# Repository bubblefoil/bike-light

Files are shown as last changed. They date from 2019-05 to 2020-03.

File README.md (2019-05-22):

# Cargo bike illumination

Cusomized bicycle RGB LED strip illumination controlled by Arduino UNO

# TODO
## Rezimy
- __Nocni:__ svitit vpredu max intenzitou (cca 6 LED z kraje), zbytek do konce nosice prichciple. To same v cervene vzadu.
- __Denni:__ To same co nocni, akorat ty prichciple nesviti vubec (stejne by to nebylo videt)
- __Parkovacky:__ sviti to prichciple cele, pricemz by bylo hezke umet menit intenzitu.
- __Blinkry:__ Max intenzivne oranzove z kraje prvnich cca 12LED prerusovane (oranzova/zhasnuto) a zbytek pri dennim nic a nocnim prichciple (bila ^ cervena)

## Rezimy 2.0

- __OFF:__ Vse 0%. Nejaka indikace?
- __Auto:__
  - Stred: 100%
  - Strany: Podle senzoru. Viz tabulka niz. Moznost menit citlivost stejne jako nastaveni jasu, tj. drzenim prepinace rezimu. Melo by stacit posouvat hranici sero/svetlo, kdy se strany vypinaji.
- __Manual:__
  - Vse podle hodnoty nastavene drzenim prepinace rezimu: 0-100%
  - 0-50%
    - Stred: 10-100%
    - Strany: Vypnute
  - 50-100%
    - Stred: 100%
    - Strany: 0-100%
- __Parking:__
  - Jas podle hodnoty nastavene drzenim prepinace rezimu: 0-100%
  - Vse sviti stejne
- __Usporny rezim:__
  - Jas podle hodnoty nastavene drzenim prepinace rezimu: 0-100%
  - Stred: Blikani (plynule pulzovani? Animace jednotlivych LED?)
  - Strany: Vypnute
  - Zmensit jas/sirku blinkru?

| Senzor | Jas [%] |
| --- | --- |
| Tma | ~1 |
| Sero | ~25 |
| Svetlo | 0 |

> To by bylo v prvni verzi vsechno. Couvacky, signalizace zamykani, kradeni, svetelna houkacka, vykreslovani bassu hudby apod.nechame na pozdeji ;)

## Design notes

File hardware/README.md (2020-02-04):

# Controller HW diagram

The cargo bike is already equiped with its own 12V battery.

Controller is programmed to work with 3 switches. A couple for turn signals and one with press/hold functions to switch light modes and control brightness.
There are [motorcycle switches like this](https://www.banggood.com/22mm-Handlebar-Light-Horn-OnOff-Signal-Indicator-Switch-For-Motorcycle-E-bike-p-1211467.html) available on the market.

Controller schema - SVG

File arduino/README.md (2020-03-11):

# Lights control unit software

Arduino application / LED strip driver.
Supplies data for WS2812B based addressable LED strips.
Uses 3 buttons as input, one for selecting light mode and changing brightness, the other two activate turn signals.

Additionally, the unit is prepared to measure ambient light by a photoresistor and battery voltage level.

It is planned to decode data on serial input as commands so the unit may be controlled via HT-05 bluetooth module. This will require solving the conflict with FastLED, which disables interrupts during feeding the strips and incoming serial data are lost.

## Development

Application is developed with [PlatformIO](https://platformio.org/platformio-ide), which has better dependency management and works with clean C++ code instead of special .ino files.

## TODO List

* Ligths off when blinking in every mode
* Implement power saving mode - blinking
* Switch to power saving mode on low battery voltage
* Less bright blinkers in power saving mode
* Fix Serial issue #2
* Animate blinkers
* Animate light changes

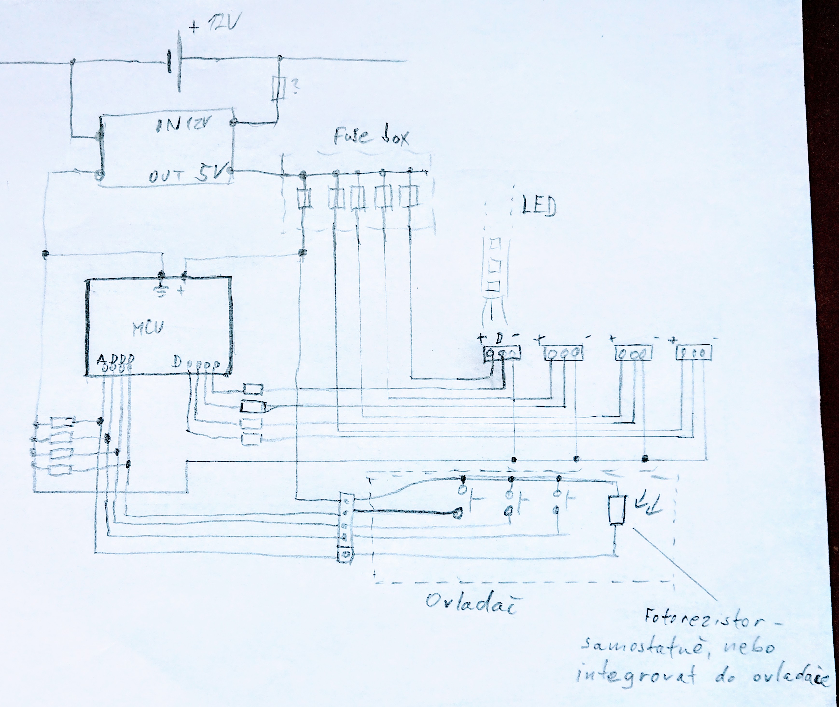
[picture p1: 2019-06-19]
hardware/Sketch.JPG

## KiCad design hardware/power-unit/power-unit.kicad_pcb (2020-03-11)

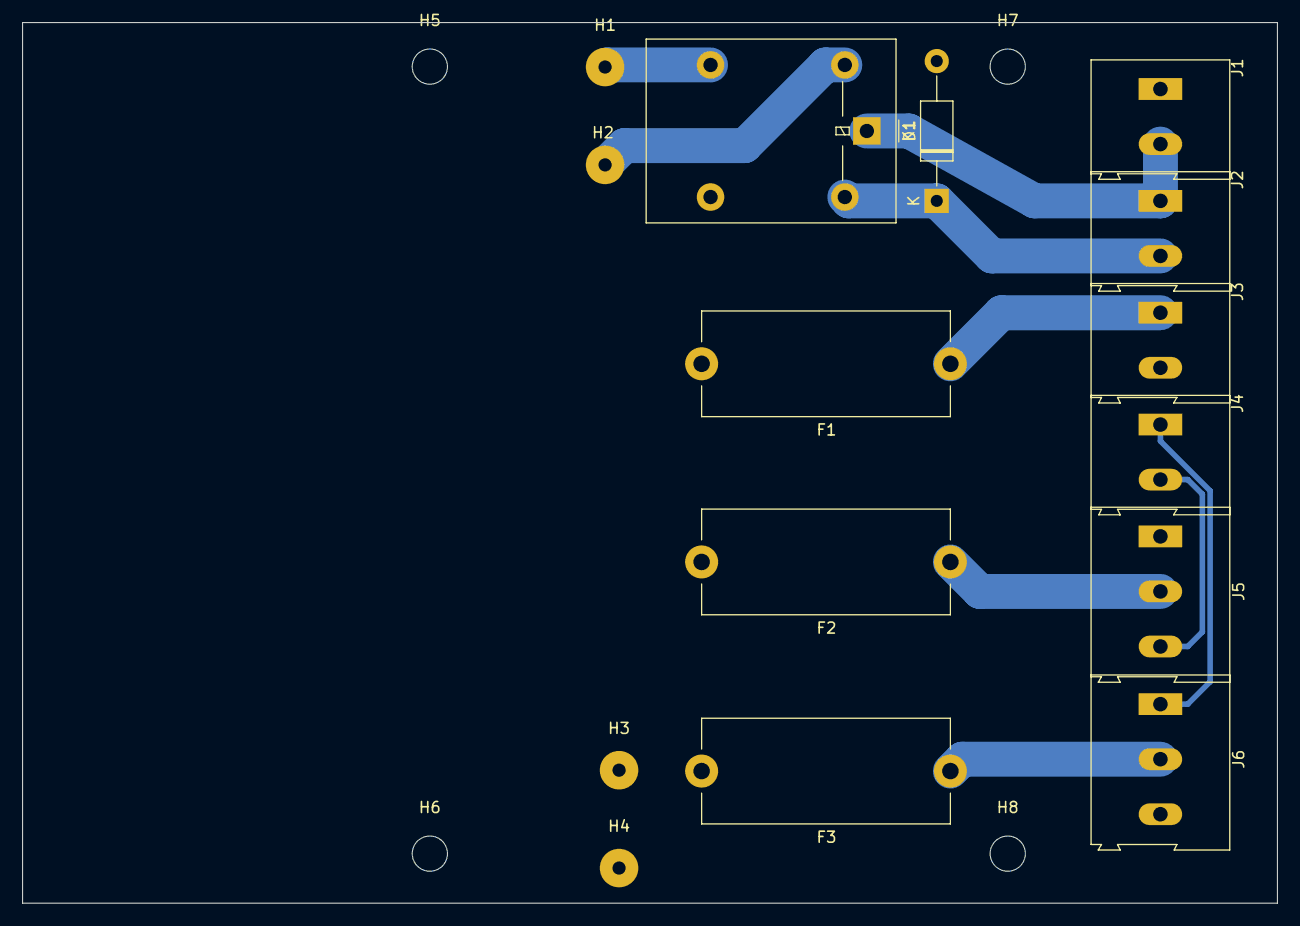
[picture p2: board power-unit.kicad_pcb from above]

Board: 2 copper layers, 114.0 x 80.0 mm, 19 parts (0 on the bottom side), 11 nets.

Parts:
D1: D; D_DO-41_SOD81_P12.70mm_Horizontal
F1: 5A; Fuseholder_Cylinder-5x20mm_Stelvio-Kontek_PTF78_Horizontal_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
F2, F3: 2.5A; Fuseholder_Cylinder-5x20mm_Stelvio-Kontek_PTF78_Horizontal_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
H1: VCC; SolderWirePad_1x01_Drill1.2mm
H2, H4: GND; SolderWirePad_1x01_Drill1.2mm
H3: +5V; SolderWirePad_1x01_Drill1.2mm
H5, H6, H7, H8: MountingHole; MountingHole_3.2mm_M3
J1: VCC; TerminalBlock_Altech_AK300-2_P5.00mm
J2: PWR Switch; TerminalBlock_Altech_AK300-2_P5.00mm
J3: 5V out; TerminalBlock_Altech_AK300-2_P5.00mm
J4: Rear LED data; TerminalBlock_Altech_AK300-2_P5.00mm
J5: LED left; TerminalBlock_Altech_AK300-3_P5.00mm
J6: LED right; TerminalBlock_Altech_AK300-3_P5.00mm
K1: G5LE-1; Relay_SPDT_Omron-G5LE-1

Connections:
+5V: F1.2, F2.2, F3.2, H3.1
BAT+: J1.2, J2.1, K1.1
GND: H4.1, J3.2, J5.1, J6.3
GNDPWR: D1.2, H2.1, J1.1, K1.2
unnamed: F1.1, J3.1
unnamed: F2.1, J5.2
unnamed: F3.1, J6.2
unnamed: H1.1, K1.3
unnamed: J4.1, J6.1
unnamed: J4.2, J5.3
PRWSW: D1.1, J2.2, K1.5

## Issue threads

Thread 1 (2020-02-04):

Change buttons to PullUp and use Arduino's integrated PullUp resistor

bubblefoil, 2020-02-04:
No need for external pull-down resistors!
https://www.brainy-bits.com/arduino-input-pullup-tutorial/

Closed 2020-02-21.

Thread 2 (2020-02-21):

Do not update LED strips unless colors change to enable reading from Serial

bubblefoil, 2020-02-21:
https://github.com/FastLED/FastLED/wiki/Interrupt-problems

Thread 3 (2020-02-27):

Prevent backpowering AVR via battery voltmeter

bubblefoil, 2020-02-27:
When the main power switch is flipped to ON, it will connect the battery voltage to an analog pin of AVR. With some delay, this voltage activates a relay which connects battery to the DC-DC converter, which powers AVR. During this delay, AVR may receive power from the analog input and burn.
This may not apply with the high-resistance voltage divider in the way, but check this out before connecting the battery.
https://forum.arduino.cc/index.php?topic=65840.0

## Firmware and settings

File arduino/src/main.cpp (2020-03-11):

#include <Arduino.h>
#include <FastLED.h>
#include "Button.h"
#include "Light.h"

// Total number of LEDs in the strip
#define NUM_LEDS 36
// Control the LED strips
#define DATA_PIN_FL 2
#define DATA_PIN_FR 3
#define DATA_PIN_BL 5
#define DATA_PIN_BR 4

// TBD - Bluetooth communication
#define RX 6
#define TX 7

// Digital input pins for buttons
#define pinLightMode 11
#define pinTurnLeft 10
#define pinTurnRight 12

const int pinPhotoResistor = A0;
const int pinBatteryVoltage = A4;

// Default light mode. Set to OFF mainly for development with just USB power.
const byte OFF = 0;
byte lightMode = OFF;

// Millis until button press is interpreted as holding.
const unsigned int holdThresholdTime = 300;
// Last mode button hold duration. Used to find time increment for gradual brightness change.
unsigned int lastHoldTime = 0;
// Sign of the brightness increment. Flipped every time the button is held and released. Do not use byte, it is unsigned!
int brightnessChangeDirection = 1;

//Left blinker
const byte LEFT = 11;
//Right blinker
const byte RIGHT = 12;
//Blinker light hue in the range from 0 - red to 255 - red again
const byte BLINKER_HUE = 24;
// Total duration of a single ON/OFF blink in milliseconds.
const unsigned long turnSignalInterval = 1000L;

// Number of head/tail light LEDs. These shine at full brightness.
const int N_FRONTAL = 6;
// Number of turn signal LEDs
const byte N_TURN_SIG = 12;

// Memory for all LED values
CRGB ledsFL[NUM_LEDS];
CRGB ledsFR[NUM_LEDS];
CRGB ledsBL[NUM_LEDS];
CRGB ledsBR[NUM_LEDS];

//LED arrays
Lights lights = Lights(ledsFL, ledsFR, ledsBL, ledsBR, NUM_LEDS, NUM_LEDS, NUM_LEDS, NUM_LEDS);

// Individual light modes.
// Classes implement abstract class LightMode with updateLights and changeBrightness methods.
LightsOff lightsOff = LightsOff(lights);
AdaptiveToAmbientLight adaptiveToAmbientLight = AdaptiveToAmbientLight(lights, pinPhotoResistor, N_FRONTAL);
ManualBrightnessLight manualBrightnessLight = ManualBrightnessLight(lights, N_FRONTAL);
ParkingLights parkingLights = ParkingLights(lights);

/** Array of pointers to the light modes. Cycled through when switching modes.
* These have to be pointers, otherwise modes would be stored and used by value, but through a LightMode referece,
* which causes "object slicing" and caling the base method instead of derived.
* https://stackoverflow.com/questions/274626/what-is-object-slicing
*/
LightMode *lightModes[] = {
    &lightsOff,
    &adaptiveToAmbientLight,
    &manualBrightnessLight,
    &parkingLights,
};

// Forward prototype declaration because of the default parameter.
void updateLights(bool show = true);

//Temporary variable to test brightness control.
byte globalBrightness = 255;

// Controls light mode. Holding the button changes brightness.
Button buttonLightMode = Button(pinLightMode, BUTTON_PULLUP_INTERNAL, true, 50);
Button buttonBlinkerLeft = Button(pinTurnLeft, BUTTON_PULLUP_INTERNAL, true, 50);
Button buttonBlinkerRight = Button(pinTurnRight, BUTTON_PULLUP_INTERNAL, true, 50);

/**
 * Changes light mode to the next one, in a circle.
 */
void nextLightMode()
{
  lightMode++;
  lightMode %= (sizeof(lightModes) / sizeof(LightMode *));
  Serial.print("Light mode: ");
  Serial.println(lightMode);
  updateLights();
}

void nextLightModeHandler(Button &b)
{
  nextLightMode();
}

/**
 * Release button handler which is active during holding event.
 * When the button is release after a hold event, the release hanlder is set back to its normal light mode change function.
 * Also the brightness change direction is flipped so when the button is held again, it makes the opposite change of brightness.
 */
void activateLightModeChangeHandler(Button &b)
{
  brightnessChangeDirection *= -1;
  Serial.print("*^ ");
  Serial.println(brightnessChangeDirection);
  b.releaseHandler(nextLightModeHandler);
}

/**
 * When a hold event is triggered, this hold handler changes Button release handler not to change Light mode,
 * because user is changing brightness. 
 */
void activateBrightnessChangeMode(Button &b)
{
  // Deactivate click handler to ignore the last click, triggered by button hold.
  // This handler will reactivate the original light mode change click handler.
  b.releaseHandler(activateLightModeChangeHandler);
}

void turnOffBlinker(Button &b)
{
  updateLights();
}

void readAmbientLight(Button &b)
{
  Serial.print("Light:");
  Serial.println(analogRead(pinPhotoResistor));
}

void processSerialInput()
{
  // FIXME: Serial input is busy when FastLED writes to strips.
  // https://github.com/FastLED/FastLED/wiki/Interrupt-problems
  while (Serial.available() > 0)
  {
    String receivedText = Serial.readString();
    Serial.println(receivedText);
    char state = receivedText[0];
    if (state >= '0' && state < (sizeof(lightModes) / sizeof(LightMode *)))
    {
      lightMode = (byte)state;
    }
    else
    {
      switch (state)
      {
      case '+':
        lightModes[lightMode]->brightnessChange(100, MORE);
        break;
      case '-':
        lightModes[lightMode]->brightnessChange(100, LESS);
        break;
      case 'm':
        nextLightMode();
        break;
      default:
        break;
      }
    }
  }
}

void handleBlinkers();
void blink(unsigned int blinkerOnTime, byte side);
void frontLeft(const CHSV &col);
void frontRight(const CHSV &col);
void rearLeft(const CHSV &col);
void rearRight(const CHSV &col);
void frontalArea();

/**
 * Initialization when Arduino is turned on.
*/
void setup()
{
  Serial.begin(9600);
  Serial.println("Arduino ON.");

  pinMode(pinPhotoResistor, INPUT); // Set pinPhotoResistor - A0 pin as an input (optional)

  // Setup buttons
  buttonLightMode.releaseHandler(nextLightModeHandler);
  buttonLightMode.holdHandler(activateBrightnessChangeMode, 300);
  //TODO try reactivating mode change on release. Modify the lib to keep firing hold events. Use this handler to change brightness.

  //Make sure lights are reset when a blinker is turned off.
  buttonBlinkerLeft.releaseHandler(turnOffBlinker);
  buttonBlinkerRight.releaseHandler(turnOffBlinker);

  // Temp ambient light sensor test
  buttonBlinkerLeft.pressHandler(readAmbientLight);
  buttonBlinkerRight.pressHandler(readAmbientLight);

  FastLED.addLeds<NEOPIXEL, DATA_PIN_FL>(ledsFL, NUM_LEDS);
  FastLED.addLeds<NEOPIXEL, DATA_PIN_FR>(ledsFR, NUM_LEDS);
  FastLED.addLeds<NEOPIXEL, DATA_PIN_BL>(ledsBL, NUM_LEDS);
  FastLED.addLeds<NEOPIXEL, DATA_PIN_BR>(ledsBR, NUM_LEDS);

  updateLights();
}

/**
 * Main Arduino's infinite loop.
*/
void loop()
{
  buttonLightMode.process();
  void processSerialInput();

  //todo Cannot use heldFor() because it checks whether hold event has already been fired. Use better timing here.
  unsigned int holdTime = buttonLightMode.holdTime();
  if (buttonLightMode.heldFor(holdThresholdTime) && holdTime > lastHoldTime)
  {
    lightModes[lightMode]->brightnessChange(holdTime - lastHoldTime, brightnessChangeDirection);
    lastHoldTime = holdTime;
  }
  else
  {
    lastHoldTime = holdThresholdTime;
  }

  updateLights(false);
  handleBlinkers();
  FastLED.show();
  FastLED.delay(10);
}

void handleBlinkers()
{
  if (buttonBlinkerLeft.isPressed())
  {
    blink(buttonBlinkerLeft.holdTime(), LEFT);
  }
  else if (buttonBlinkerRight.isPressed())
  {
    blink(buttonBlinkerRight.holdTime(), RIGHT);
  }
}

/**
 * Returns true if we are in the first half of the blinker interval,
 * measured since the blinker was switched on.
 */
bool getBlinkerLightState(unsigned int switchOnTime)
{
  // Less than half the blinker interval elapsed?
  return (switchOnTime % turnSignalInterval < (turnSignalInterval / 2));
}

void blink(unsigned int blinkerOnTime, byte side)
{
  //Is the blinker light on or off at the moment?
  bool blinkerState = getBlinkerLightState(blinkerOnTime);

  if (!blinkerState)
  {
    updateLights(false);
  }

  byte brightness = blinkerState ? 255 : 0;
  CHSV blinkerColor = CHSV(BLINKER_HUE, 255, brightness);
  if (side == RIGHT)
  {
    frontRight(blinkerColor);
    rearRight(blinkerColor);
  }
  else if (side == LEFT)
  {
    frontLeft(blinkerColor);
    rearLeft(blinkerColor);
  }
}

void updateLights(bool show)
{
  LightMode *mode = lightModes[lightMode];
  mode->updateLights();

  if (show)
  {
    FastLED.show();
  }
}

void off()
{
  FastLED.clear(false);
}

void frontLeft(const CHSV &col)
{
  fill_solid(ledsFL, NUM_LEDS, col);
}

void frontRight(const CHSV &col)
{
  fill_solid(ledsFR, NUM_LEDS, col);
}

void rearLeft(const CHSV &col)
{
  fill_solid(ledsBL, NUM_LEDS, col);
}

void rearRight(const CHSV &col)
{
  fill_solid(ledsBR, NUM_LEDS, col);
}

/**
 * Lights up the frontal area of both head and tail light with white and red, respectively.
*/
void frontalArea()
{
  fill_solid(&ledsFL[NUM_LEDS - N_FRONTAL], N_FRONTAL, CRGB::White);
  fill_solid(&ledsFR[NUM_LEDS - N_FRONTAL], N_FRONTAL, CRGB::White);
  fill_solid(&ledsBL[NUM_LEDS - N_FRONTAL], N_FRONTAL, CRGB::Red);
  fill_solid(&ledsBR[NUM_LEDS - N_FRONTAL], N_FRONTAL, CRGB::Red);
}

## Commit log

2019-05-18 Add circuit image
2019-05-19 Add wiring image
2019-05-22 Simplified blinkers with a button lib. Add ambient light reading.
2019-05-29 Split LED strip into 4 pieces and rewired
2020-02-04 Added LED Strip HW Schema.svg
2020-02-04 Rename LED Strip HW Schema.svg to controller-schema.svg
2020-02-21 Back to pullup, fix BT pinout
    [mech-ctrl.ino]
2020-02-25 Added power-unit.drawio
2020-02-25 Import power-unit.drawio content
2020-02-25 Add crude pcb layout
2020-03-11 Add KiCad project for power unit
    [power-unit.kicad_pcb, power-unit.sch]
2020-03-11 Update hw schematics
